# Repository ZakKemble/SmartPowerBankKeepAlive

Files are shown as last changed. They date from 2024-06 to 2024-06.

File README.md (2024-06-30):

# Smart Power Bank Keep-Alive (v2.x)

Keep USB power banks alive when powering low-power projects with this pulsed constant current sink USB module.

[https://blog.zakkemble.net/smart-power-bank-keep-alive/](https://blog.zakkemble.net/smart-power-bank-keep-alive/)

|Hardware version|Branch|Photo|
|---|---|---|
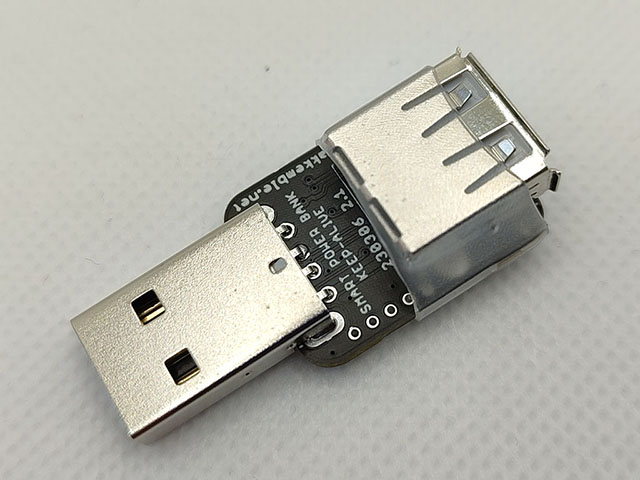
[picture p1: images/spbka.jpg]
|v2.x|[main](https://github.com/zakkemble/SmartPowerBankKeepAlive) (you are currently on this one)||
|v1.x|[v1.x](https://github.com/zakkemble/SmartPowerBankKeepAlive/tree/v1.x)||

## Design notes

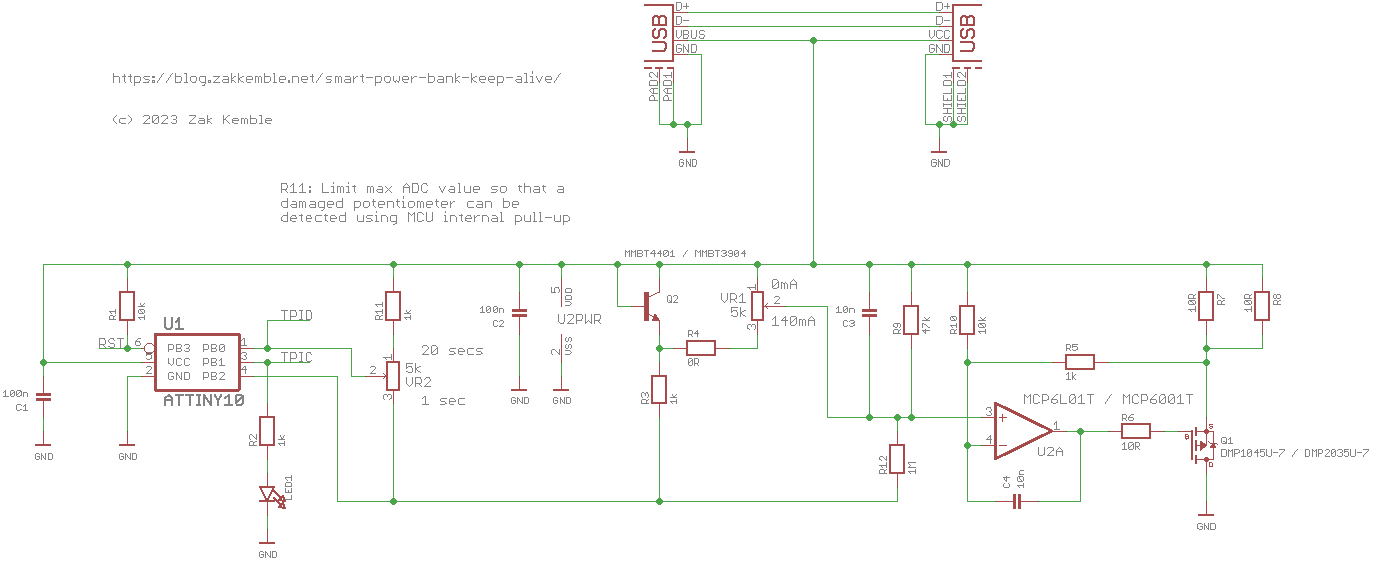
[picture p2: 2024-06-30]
hardware/schematic.png

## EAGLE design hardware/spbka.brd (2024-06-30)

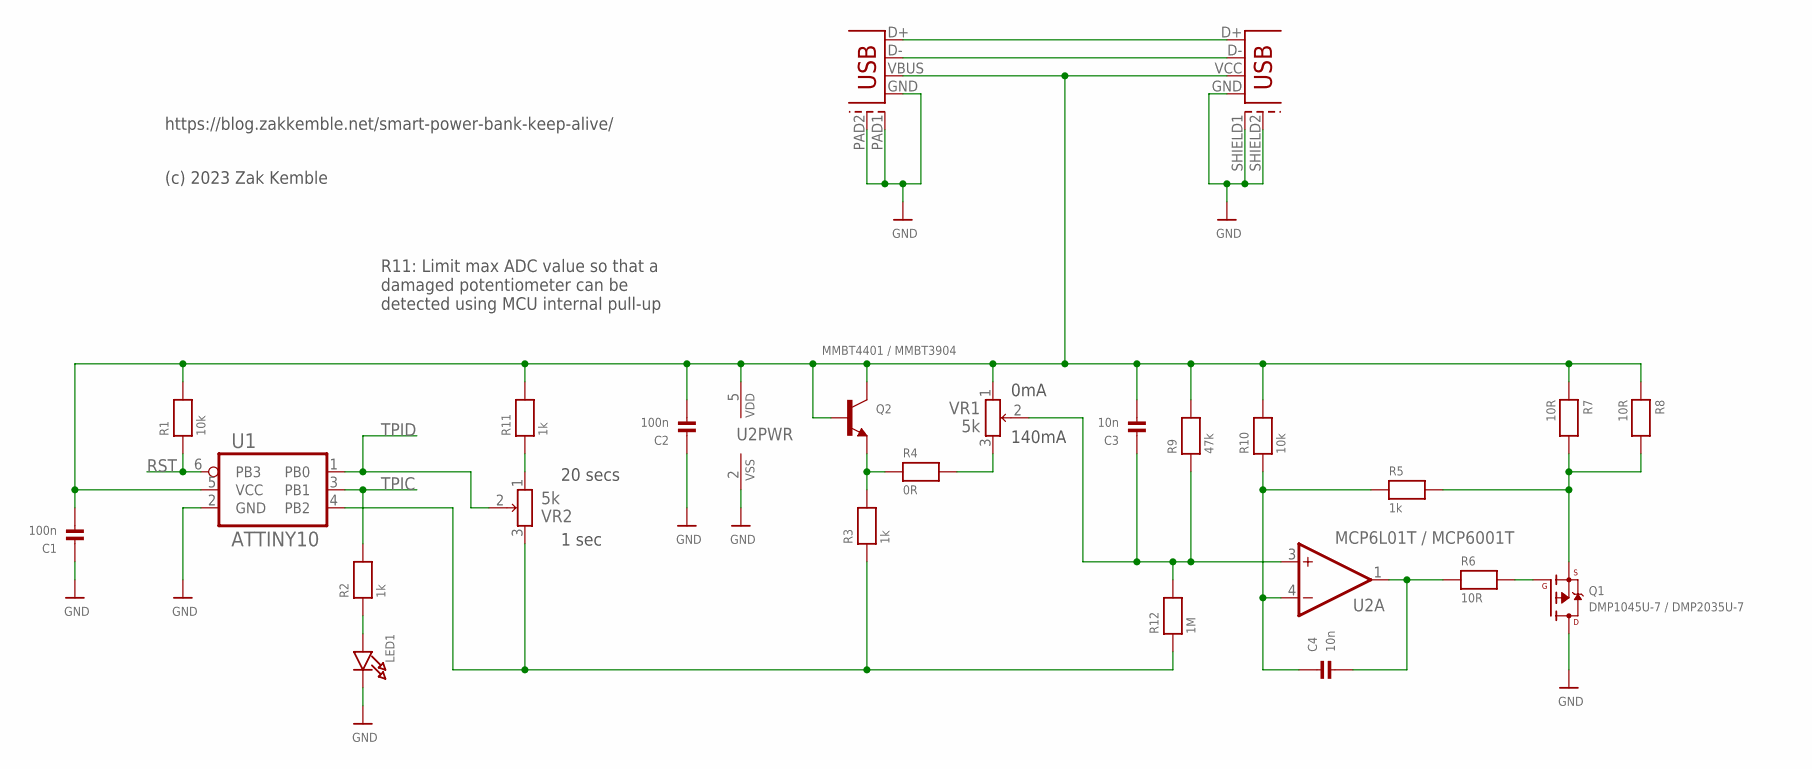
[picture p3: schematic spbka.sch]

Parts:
C1, C2: 100n; 0402_XSMALL
C3, C4: 10n; 0402_XSMALL
LED1: LED0603_NOOUTLINE; CHIPLED_0603_NOOUTLINE
Q1: DMP1045U-7 / DMP2035U-7; SOT-23-WIDE
Q2: MMBT4401 / MMBT3904; SOT23-R
R1, R10: 10k; 0402_XSMALL
R2, R3, R5, R11: 1k; 0402_XSMALL
R4: 0R; 0402_XSMALL
R6, R7, R8: 10R; 0402_XSMALL
R9: 47k; 0402_XSMALL
R12: 1M; 0402_XSMALL
U1: ATTINY10; SOT23-6_SM_PAD
U2: MCP6L01T / MCP6001T; SOT23-5_SM_PAD
USB1: USB-TYPE-AHORZ; USB-TYPE-A
USB2: USB-PLUG; USB-TYPE-A-PLUG-SLOT
VR1, VR2: 5k; TRIMPOT_BOURNS3MM

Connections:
GND: C1.1, C2.1, LED1.C, Q1.3 (D), U1.2 (GND), U2.2 (VSS), USB1.GND, USB1.SHIELD1 (SHEILD1), USB1.SHIELD2 (SHEILD2), USB2.GND, USB2.PAD1 (SHEILD1), USB2.PAD2 (SHEILD2)
unnamed: Q2.2 (E), R3.2, R4.1
unnamed: Q1.2 (S), R5.2, R7.2, R8.2
unnamed: C4.2, R6.1, U2.1 (OUT)
unnamed: LED1.A, R2.1
unnamed: USB1.D+, USB2.D+
unnamed: USB1.D-, USB2.D-
unnamed: R3.1, R12.1, U1.4 (PB2), VR2.3 (1E)
unnamed: C4.1, R5.1, R10.1, U2.4 (-IN)
unnamed: R4.2, VR1.3 (1E)
unnamed: Q1.1 (G), R6.2
unnamed: C3.1, R9.1, R12.2, U2.3 (+IN), VR1.2 (1S)
unnamed: R11.1, VR2.1 (1A)
RST: R1.1, U1.6 (PB3)
TPIC: R2.2, U1.3 (PB1)
TPID: U1.1 (PB0), VR2.2 (1S)
VBUS: C1.2, C2.2, C3.2, Q2.1 (B), Q2.3 (C), R1.2, R7.1, R8.1, R9.2, R10.2, R11.2, U1.5 (VCC), U2.5 (VDD), USB1.VCC (VBUS), USB2.VBUS, VR1.1 (1A)

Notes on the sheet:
0mA
140mA
https://blog.zakkemble.net/smart-power-bank-keep-alive/
(c) 2023 Zak Kemble
20 secs
1 sec
R11: Limit max ADC value so that a damaged potentiometer can be detected using MCU internal pull-up

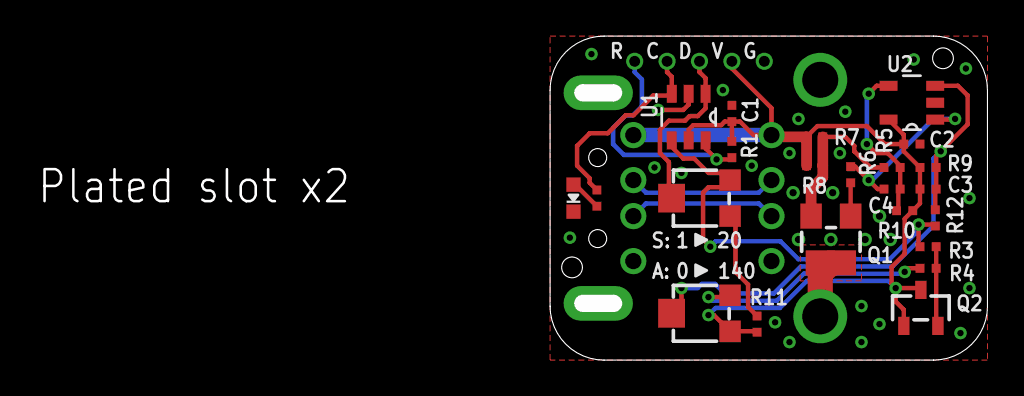
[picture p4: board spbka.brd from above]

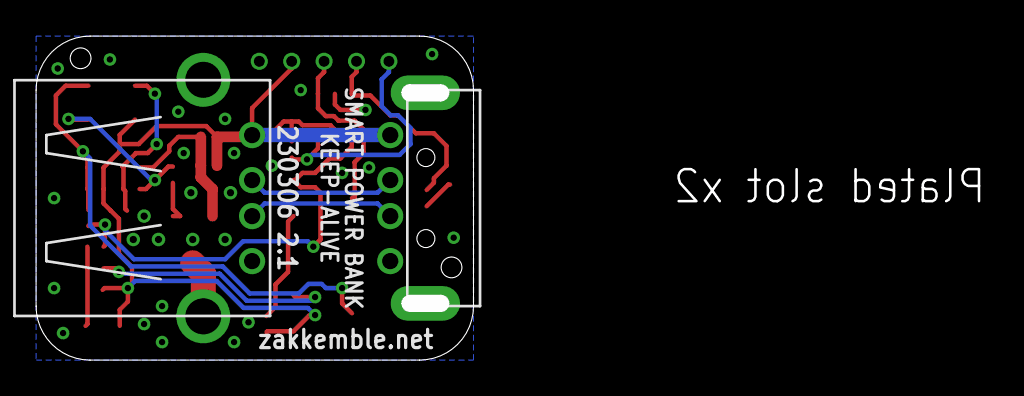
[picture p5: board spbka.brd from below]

Board: 2 copper layers, 24.3 x 18.0 mm, 25 parts (2 on the bottom side), 17 nets.

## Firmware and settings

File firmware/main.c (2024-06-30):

// Smart Power Bank Keep-Alive
// https://blog.zakkemble.net/smart-power-bank-keep-alive/
// https://github.com/ZakKemble/SmartPowerBankKeepAlive
// Copyright (C) 2023, Zak Kemble

#include <stdint.h>
#include <avr/io.h>
#include <avr/power.h>
#include <avr/sleep.h>
#include <avr/interrupt.h>
#include <avr/wdt.h>

// PB0: Unused / Off-time ADC0 input
// PB1: LED output (HIGH = on)
// PB2: CC enable output (LOW = enable)

#define ADC_VAL_PER_SEC		11

#define WDT_INT_RESET()		(WDTCSR |= _BV(WDIE)|_BV(WDE)) // NOTE: Setting WDIE also enables global interrupts
#define WDT_TIMEDOUT()		(!(WDTCSR & _BV(WDIE)))

void __attribute__((naked, used, section(".init3"))) get_rstflr(void)
{
	RSTFLR = 0;
	wdt_disable();
}

static void waitForWDT(uint8_t wdto)
{
	wdt_enable(wdto);
	WDT_INT_RESET();
	
	sleep_enable();
	//sleep_bod_disable();
	//sei();
	sleep_cpu();
	sleep_disable();
}

static void fadeIn(void)
{
	set_sleep_mode(SLEEP_MODE_IDLE);

	// Enable LED PWM timer
	power_timer0_enable();
	OCR0B = 0;
	TCCR0A |= _BV(COM0B1);

	// ~500ms
	// LED Fade in
	for(uint8_t i=0;i<32;i++)
	{
		waitForWDT(WDTO_15MS);
		OCR0BL = (i < 31) ? OCR0BL + 8 : 255;
	}

	// Disable LED PWM timer
	TCCR0A &= ~_BV(COM0B1);
	power_timer0_disable();

	set_sleep_mode(SLEEP_MODE_PWR_DOWN);
}

static void fadeOut(void)
{
	set_sleep_mode(SLEEP_MODE_IDLE);

	// Enable LED PWM timer
	power_timer0_enable();
	TCCR0A |= _BV(COM0B1);

	// ~500ms
	// LED Fade out
	for(uint8_t i=0;i<32;i++)
	{
		waitForWDT(WDTO_15MS);
		OCR0BL = (i < 31) ? OCR0BL - 8 : 0;
	}

	// Disable LED PWM timer
	TCCR0A &= ~_BV(COM0B1);
	power_timer0_disable();

	set_sleep_mode(SLEEP_MODE_PWR_DOWN);
}

static inline void ccOn(void)
{
	PORTB = _BV(PORT1);
}

static inline void ccOff(void)
{
	PORTB = _BV(PORT2);
}

static void waitOn(void)
{
	waitForWDT(WDTO_2S);
}

static void waitOff(uint8_t seconds)
{
	while(1)
	{
		waitForWDT(WDTO_1S);
		seconds -= ADC_VAL_PER_SEC;
		if(seconds > (255 - ADC_VAL_PER_SEC))
			break;
	}
}

static uint8_t getOffTime(void)
{
	power_adc_enable();
	ADCSRA = _BV(ADEN)|_BV(ADSC)|_BV(ADPS2)|_BV(ADPS0); // Div32 = 125KHz
	while(ADCSRA & _BV(ADSC));
	uint8_t adcTimeVal = ADCL;
	power_adc_disable();
	
	// 5k pot with 1k on Vin + internal pullup
	// @5V
	// Max: 4.16V = 212 (219 with +25% tolerance, 201 with -25% tolerance)
	// Min: 0V = 0
	
	// If the pot has gone bad (wiper has disconnected) then the ADC input
	// will be pulled up to VCC via the internal pullup and read ~255.
	// Default to 6 seconds when this happens.
	if(adcTimeVal > 220)
		adcTimeVal = ADC_VAL_PER_SEC * 6;
	
	return adcTimeVal;
}

int main(void)
{
	clock_prescale_set(CPU_DIV);

	// Configure pins
	DDRB |= _BV(DDB2)|_BV(DDB1); // Outputs
	PUEB |= _BV(PUEB0); // Pullups

	// Configure LED PWM fade timer
	TCCR0A = _BV(WGM00);
	TCCR0B = _BV(WGM02)|_BV(CS01);

	// Configure ADC
	//ADMUX = 0; // ADC0/PB0
	DIDR0 = _BV(ADC0D);

	ACSR = _BV(ACD); // Power off analog comparator
	power_all_disable(); // Power off everything else

	sei();

	while(1)
	{
		// On period
		ccOn();
		fadeIn();
		waitOn();
		fadeOut();

		// Off period
		uint8_t offTime = getOffTime();
		ccOff();
		waitOff(offTime);
	}
}

EMPTY_INTERRUPT(WDT_vect);

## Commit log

2020-02-10 Initial commit :sweat_drops:
    [spbka.brd, spbka.sch]
2020-05-16 Some small changes, HW v1.2
    Hardware bumped to v1.2:
    Added unmasked vias for VCC and GND to make it easier to program.
    Made USB3 socket pads longer (some components and things had to be moved slightly for this).
    [spbka.brd, spbka.sch]
2024-06-30 hardware v2.1
    [spbka.brd, spbka.sch]

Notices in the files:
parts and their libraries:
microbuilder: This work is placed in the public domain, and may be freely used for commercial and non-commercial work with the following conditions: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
